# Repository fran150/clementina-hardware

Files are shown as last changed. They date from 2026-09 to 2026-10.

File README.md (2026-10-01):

# Clementina Hardware

KiCad 9 schematic and board for Clementina, a 3.3 V homebrew computer built
around a W65C02S CPU. A Raspberry Pi Pico 2 W, called MIA, runs the machine: it
generates the CPU clock, boots the kernel, and provides video, audio, storage
and input.

Status: the rev 1 schematic is complete and ERC-clean, and the rev 1 board is
laid out, fully routed and DRC-clean. The first build is planned on
protoboard, using the same parts as the board.

## Opening the project

Open `clementina-hardware.kicad_pro` in KiCad 9.

- `clementina.kicad_sym` (listed in `sym-lib-table`) holds the parts KiCad's
  own libraries lack, currently the AS6C62256 SRAM.
- The W65C02S and W65C22S symbols come from KiCad's Plugin and Content Manager
  (library `PCM_65xx-library`). The schematic carries copies, so it opens
  without that library. Install it to keep ERC's library check clean.
- One ERC item is excluded on purpose: the Pico's AGND tied to GND. The ADC is
  unused, and the Pico datasheet allows the join.
- `clementina-hardware.kicad_dru` holds one custom DRC rule: the audio jack's
  barrel hangs over the board edge on purpose, so its silkscreen outline may
  cross the edge.
- DRC shows one warning, and it is expected: the Pico footprint "does not
  match the copy in the library". The library's antenna keep-out lists 32
  copper layers, and a 2-layer board keeps only two of them.

Sheets:

| Sheet | Contents |
| --- | --- |
| `clementina-hardware.kicad_sch` (A3) | CPU, VIA, RAM, MIA, IRQ and reset circuits, expansion headers, user port, audio output, microSD, power and decoupling |
| `CS Logic.kicad_sch` | Address decoding (74AC138 x2, 74AC08, two gates of the 74AC00) |
| `OE_RW_PHI2_Sync.kicad_sch` | Read and write strobes: `~OE` from R/W, `~WE` qualified by PHI2 (two gates of the 74AC00) |

## Architecture

| Part | Role |
| --- | --- |
| W65C02S (U1) | CPU. MIA drives PHI2: 1.2 MHz by default, up to 8 MHz. |
| AS6C62256 (U4) | 32 KB base RAM |
| AS6C4008 (U2) | 512 KB extended RAM, seen through a 16 KB window |
| W65C22S (U3) | VIA. Port A selects the extended RAM bank; port B and CA/CB go to the user port. |
| Raspberry Pi Pico 2 W (A1) | MIA: clock, boot loader, video over Wi-Fi, audio, microSD, input, reset |
| 74AC138 x2, 74AC08, 74AC00 | Glue logic (see [Glue logic timing](#glue-logic-timing)) |

Memory map:

| Range | Device |
| --- | --- |
| `$0000-$7FFF` | Base RAM |
| `$8000-$BFFF` | Extended RAM window (32 banks, selected by VIA PA0-PA4) |
| `$C000-$DFFF` | I/O: eight 1 KB slots. Slot 0 (`$C000`) is the VIA; slots 1-7 go to the expansion headers. |
| `$E000-$FFFF` | MIA (registers at `$FFE0-$FFFF`) |

MIA's pins:

| GPIO | Signal |
| --- | --- |
| GP0-GP3 | microSD (SPI0: MISO, CS, SCK, MOSI) |
| GP4, GP5 | Audio left and right (PWM) |
| GP6 | MIA chip select |
| GP7 | R/W |
| GP8-GP15 | D0-D7 |
| GP16-GP20 | A0-A4 |
| GP21 | PHI2 |
| GP22 | IRQ |
| GP26 | RESB (MIA holds the CPU and VIA in reset) |
| GP27 | Reset request from the RESET button |
| GP28 | Unused |

### Glue logic timing

The glue logic is 74AC, not 74HC, because 74HC is slow at 3.3 V (roughly
13 ns per gate typical, up to about 30 ns). Two places depend on it:

- **Write strobe.** `~WE = NAND(PHI2, ~OE)` in one 74AC00 gate, so `~WE`
  rises within about 10 ns of PHI2 falling. The W65C02S only guarantees its
  address and data for 10 ns after PHI2 falls, and the SRAMs need both held
  until `~WE` rises. This timing doesn't depend on clock speed, so running
  slower doesn't help. The Picocomputer RP6502 makes WE# the same way.
- **Chip selects.** The VIA and the expansion cards need their chip select
  10 ns before PHI2 rises. U6 is enabled straight from A13-A15 (A15
  through one inverting gate), not through U8, which removes a decoder level
  from those selects.

With 74AC parts, the chip-select paths meet the datasheets up to about
6.5 MHz with worst-case parts, and typical parts reach 8 MHz. 74HC parts give
the same logic but lose the write-strobe guarantee, and the VIA's chip select
limits them to about 3.5 MHz worst case.

Interrupts are wired-AND: MIA and the VIA each pull `~IRQB` low through a BAT85
Schottky diode against a 4.7 kΩ pull-up. `~NMI` (4.7 kΩ) and RDY (2.2 kΩ) are
also pulled up, so expansion cards can use them. RDY is also an output: the
CPU pulls it low while it executes `WAI`. The W65C02S only guarantees 1.6 mA
at 0.4 V there, so the RDY pull-up can't be stronger than about 2 kΩ.

## Power (rev 1)

Everything runs from the Pico's USB. Its 3V3 output supplies the whole board,
and VBUS supplies the `+5V` pins on the headers.

- Keep the external 3.3 V load under about 300 mA. The board uses roughly
  50 mA idle and 150 mA with the microSD card writing, which leaves about
  150 mA for expansion cards.
- A phone charger works when no PC is attached.
- VSYS is left free for a rev 2 power input.

## Connectors

**J1, J2: expansion bus** (2x20 keyed box headers, identical)

| Pin | Signal | Pin | Signal |
| ---: | --- | ---: | --- |
| 1 | GND | 2 | +3.3V |
| 3 | A0 | 4 | A1 |
| 5 | A2 | 6 | A3 |
| 7 | A4 | 8 | A5 |
| 9 | A6 | 10 | A7 |
| 11 | A8 | 12 | A9 |
| 13 | GND | 14 | PHI2 |
| 15 | GND | 16 | RWB |
| 17 | ~OE | 18 | ~WE |
| 19 | ~RESB | 20 | ~IRQB |
| 21 | ~NMI | 22 | RDY |
| 23 | D0 | 24 | D1 |
| 25 | D2 | 26 | D3 |
| 27 | D4 | 28 | D5 |
| 29 | D6 | 30 | D7 |
| 31 | ~IOCS1 | 32 | ~IOCS2 |
| 33 | ~IOCS3 | 34 | ~IOCS4 |
| 35 | ~IOCS5 | 36 | ~IOCS6 |
| 37 | ~IOCS7 | 38 | +5V |
| 39 | GND | 40 | +3.3V |

**J3: user port** (2x10 keyed box header, VIA port B)

| Pin | Signal | Pin | Signal |
| ---: | --- | ---: | --- |
| 1 | GND | 2 | +3.3V |
| 3 | PB0 | 4 | PB1 |
| 5 | PB2 | 6 | PB3 |
| 7 | PB4 | 8 | PB5 |
| 9 | PB6 | 10 | PB7 |
| 11 | CB1 | 12 | CB2 |
| 13 | CA1 | 14 | CA2 |
| 15 | ~RESB | 16 | GND |
| 17 | GND | 18 | +5V |
| 19 | GND | 20 | +3.3V |

Rules for cards on J1-J3:

- 3.3 V logic only. Never put a 5 V signal on any pin.
- A card claims one I/O slot by jumpering one of `~IOCS1`-`~IOCS7`.
- `~IRQB`, `~NMI` and RDY: pull them low through a Schottky diode or an
  open-drain output, and never drive them high.
- RDY also goes low while the CPU executes `WAI`. Don't read RDY low as a
  wait request from another card.
- `~RESB` is driven by MIA: read it, never drive it.
- W65C22S port pins have no current limiting. Drive LEDs and similar loads
  through a resistor.

**J4: audio out.** A stereo 3.5 mm jack (CUI SJ1-3533NG, through-hole, round
pins): tip left, ring right. Each channel
uses the same output stage as the Picocomputer RP6502: a 220 Ω / 100 Ω
divider, a 100 nF filter capacitor, a 47 µF DC block and a 1.8 kΩ bleed
resistor. It gives about 1 Vpp line level and drives headphones directly. MIA
mixes at 48 kHz.

**J5: microSD.** A 1x9 female header for the Adafruit 4682 microSD breakout
(3 V only), used in SPI mode on MIA's SPI0: 400 kHz to initialise, then
12 MHz. The breakout has its own pull-ups (CS, MISO, DAT1, DAT2) and bypass
capacitors. DAT1, DAT2 and card detect stay unconnected.

| Pin | 1 | 2 | 3 | 4 | 5 | 6 | 7 | 8 | 9 |
| --- | --- | --- | --- | --- | --- | --- | --- | --- | --- |
| Breakout | 3V | GND | CLK | SO | SI | CS | DAT1 | DAT2 | DET |
| Signal | +3.3V | GND | SD_SCK | SD_MISO | SD_MOSI | SD_CS | - | - | - |

## Board (rev 1)

`clementina-hardware.kicad_pcb`: 172.7 x 108.6 mm, 2 layers, every part
through-hole. The chips sit in sockets and the Pico plugs into female headers,
so the same parts move from the protoboard build to the board.

- Layout: the MIA Pico is at the top left, with its USB port on the top edge
  and its Wi-Fi antenna over a copper keep-out. The microSD breakout sits to
  its left, with the card slot at the left board edge. The audio stage and jack
  run down the left edge, and the reset button sits well below the Pico. The CPU,
  RAM, extended RAM and VIA form one row, with the user port at the right edge.
  The glue logic is in a row below them, and the two expansion headers are
  stacked along the bottom edge.
- Every chip has a 100 nF capacitor next to its supply pin; C14 (22 µF) is by
  the Pico's 3V3 pin.
- Wi-Fi antenna: Raspberry Pi recommends putting the Pico W's antenna at a
  board edge with nothing close to it. Here it sits inside the board, as on the
  Picocomputer RP6502. The Pico stands about 10 mm up on its headers, no copper
  runs under the antenna, and a rule area ("Wi-Fi antenna clearance") keeps
  tracks, vias and ground fill about 6 mm past the Pico's end. Leave that area
  clear of parts and cables. The expected cost is a few dB of range, which the
  video protocol tolerates. To check a build, compare the Wi-Fi signal
  strength (RSSI) of the Pico on its own and on the board at the same spot; if
  the board costs more than about 6 dB, move the antenna to an edge in rev 2.
- Routing: 0.25 mm signal tracks, 0.4 mm for GND, +3.3V and +5V (net class
  `Power`), 0.2 mm clearance, and 0.6 / 0.3 mm vias. The top layer runs mostly
  horizontal and the bottom mostly vertical. Both layers carry a GND pour,
  stitched with vias. Any hobby PCB fab can make it (1.6 mm FR-4, 1 oz copper).
- The routing was produced by a script and then checked with KiCad's DRC and
  its schematic parity check. Edit it freely in KiCad.
- Silkscreen: part values are printed on the resistors and capacitors, and the
  chip names inside the socket outlines. The J5 pin names and the breakout's
  outline are printed too.
- Mounting: four M3 holes in the corners. Two M2.5 holes under the microSD
  breakout match its own holes. They're optional, to support it with
  standoffs (about 11 mm).

### Bill of materials

Every part has two schematic fields that keep the bill of materials generic,
so you can source parts yourself (for the protoboard build) or hand them to an
assembly service:

- **Factory**: what gets soldered to the board at that designator. Chips get a
  DIP socket, and the Pico (A1) gets two 1x20 female headers.
- **Plug-in**: what you plug in afterwards, if anything.

[`bom/factory-bom.csv`](bom/factory-bom.csv) lists everything that's
soldered: passives, diodes, sockets, headers, the jack and the button. With
those soldered (by you or the factory), the board needs no more soldering;
plug in these parts:

| Ref | Part |
| --- | --- |
| U1 | WDC W65C02S CPU, DIP-40 (W65C02S6TPG-14) |
| U3 | WDC W65C22S VIA, DIP-40 (W65C22S6TPG-14) |
| U4 | Alliance AS6C62256-55PCN, 32K x 8 SRAM, DIP-28 |
| U2 | Alliance AS6C4008-55PCN, 512K x 8 SRAM, DIP-32 |
| U6, U8 | 74AC138, DIP-16 |
| U7 | 74AC08, DIP-14 |
| U9 | 74AC00, DIP-14 |
| A1 | Raspberry Pi Pico 2 WH (the version with pins already soldered) |
| J5 | Adafruit 4682 microSD breakout, 3 V |

The Adafruit 4682 ships with its header loose: solder the 9 pins to the
module once, or use a breakout sold with the header fitted.

The "A1" row of the factory BOM is two headers, one per side of the Pico.

To regenerate the factory BOM after changing parts:

```
kicad-cli sch export bom --fields 'Factory,${QUANTITY},Reference' --labels 'Part,Qty,References' --group-by Factory --sort-field Reference --sort-asc -o bom/factory-bom.csv clementina-hardware.kicad_sch
```

### Fabrication files

The Gerbers are generated from the board, so they aren't committed: git
ignores `fabrication/`. Rebuild them after any board change:

```
mkdir -p fabrication/gerbers
kicad-cli pcb export gerbers --no-x2 --no-netlist --subtract-soldermask -l F.Cu,B.Cu,F.Mask,B.Mask,F.Silkscreen,Edge.Cuts -o fabrication/gerbers/ clementina-hardware.kicad_pcb
kicad-cli pcb export drill --excellon-separate-th -o fabrication/gerbers/ clementina-hardware.kicad_pcb
rm fabrication/gerbers/*.gbrjob
zip -j -FS fabrication/clementina-rev1-gerbers.zip fabrication/gerbers/*
```

Upload `fabrication/clementina-rev1-gerbers.zip` to the fab. It holds eight
files: both copper layers, both masks, the front silkscreen, the board outline,
and separate drill files for plated and unplated holes.

- `--no-x2 --no-netlist`: PCBWay's KiCad guide asks for Gerbers without X2
  attributes. With them, its upload preview showed only the holes.
- No back silkscreen: it's empty.
- `--subtract-soldermask` keeps silkscreen ink off the pads.
- The zip leaves out KiCad's `.gbrjob` job file.
- `zip -FS` also removes files that are no longer in `fabrication/gerbers/`.

When you order boards, tag the commit you ordered from and attach the zip you
uploaded to a GitHub release on that tag. That keeps a record of exactly what
was made.

## Not in rev 1

- A separate power input (USB-C into VSYS) with a jumper to power a USB
  keyboard on the Pico's port
- Local video output, likely a second Pico as a display client

## Related repositories

- [clementina-6502](https://github.com/fran150/clementina-6502): emulator
- [clementina-mia](https://github.com/fran150/clementina-mia): MIA firmware
- [clementina-rom](https://github.com/fran150/clementina-rom): kernel,
  BASIC and WozMon
- [clementina-sdk](https://github.com/fran150/clementina-sdk): development SDK
- [clementina-studio](https://github.com/fran150/clementina-studio): asset
  editor
- [clementina-video-client](https://github.com/fran150/clementina-video-client):
  video client

## License

GPLv3. See [LICENSE](LICENSE).

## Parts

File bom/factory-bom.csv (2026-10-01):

Part | Qty | References
2 x female header 1x20, 2.54 mm, 8.5 mm tall (both at A1, one per Pico side) | 1 | A1
Ceramic capacitor 1 µF, 50 V, X7R, radial, 5.08 mm lead spacing | 1 | C1
Electrolytic capacitor 22 µF, 16 V, radial, 5 mm diameter, 2.5 mm lead spacing | 1 | C14
Ceramic capacitor 100 nF, 50 V, X7R, radial, 5.08 mm lead spacing | 10 | C2,C4,C6-C13
Electrolytic capacitor 47 µF, 16 V, radial, 5 mm diameter, 2.5 mm lead spacing | 2 | C3,C5
BAT85 Schottky diode, DO-34 | 2 | D1,D2
IDC box header 2x10, 2.54 mm, vertical | 1 | J3
3.5 mm stereo jack, CUI SJ1-3533NG or same footprint | 1 | J4
Female header 1x9, 2.54 mm, 8.5 mm tall | 1 | J5
IDC box header 2x20, 2.54 mm, vertical | 2 | J1,J2
Resistor 2.2 kΩ, 1/4 W, 1% metal film, axial, 10.16 mm lead spacing | 1 | R1
Resistor 10 kΩ, 1/4 W, 1% metal film, axial, 10.16 mm lead spacing | 1 | R3
Resistor 4.7 kΩ, 1/4 W, 1% metal film, axial, 10.16 mm lead spacing | 2 | R2,R5
Resistor 100 Ω, 1/4 W, 1% metal film, axial, 10.16 mm lead spacing | 3 | R4,R7,R10
Resistor 220 Ω, 1/4 W, 1% metal film, axial, 10.16 mm lead spacing | 2 | R6,R9
Resistor 1.8 kΩ, 1/4 W, 1% metal film, axial, 10.16 mm lead spacing | 2 | R8,R11
Tactile switch 6 x 6 mm, through-hole | 1 | SW1
DIP-32 socket, 15.24 mm (0.6 in) rows | 1 | U2
DIP-28 socket, 15.24 mm (0.6 in) rows | 1 | U4
DIP-40 socket, 15.24 mm (0.6 in) rows | 2 | U1,U3
DIP-16 socket, 7.62 mm (0.3 in) rows | 2 | U6,U8
DIP-14 socket, 7.62 mm (0.3 in) rows | 2 | U7,U9

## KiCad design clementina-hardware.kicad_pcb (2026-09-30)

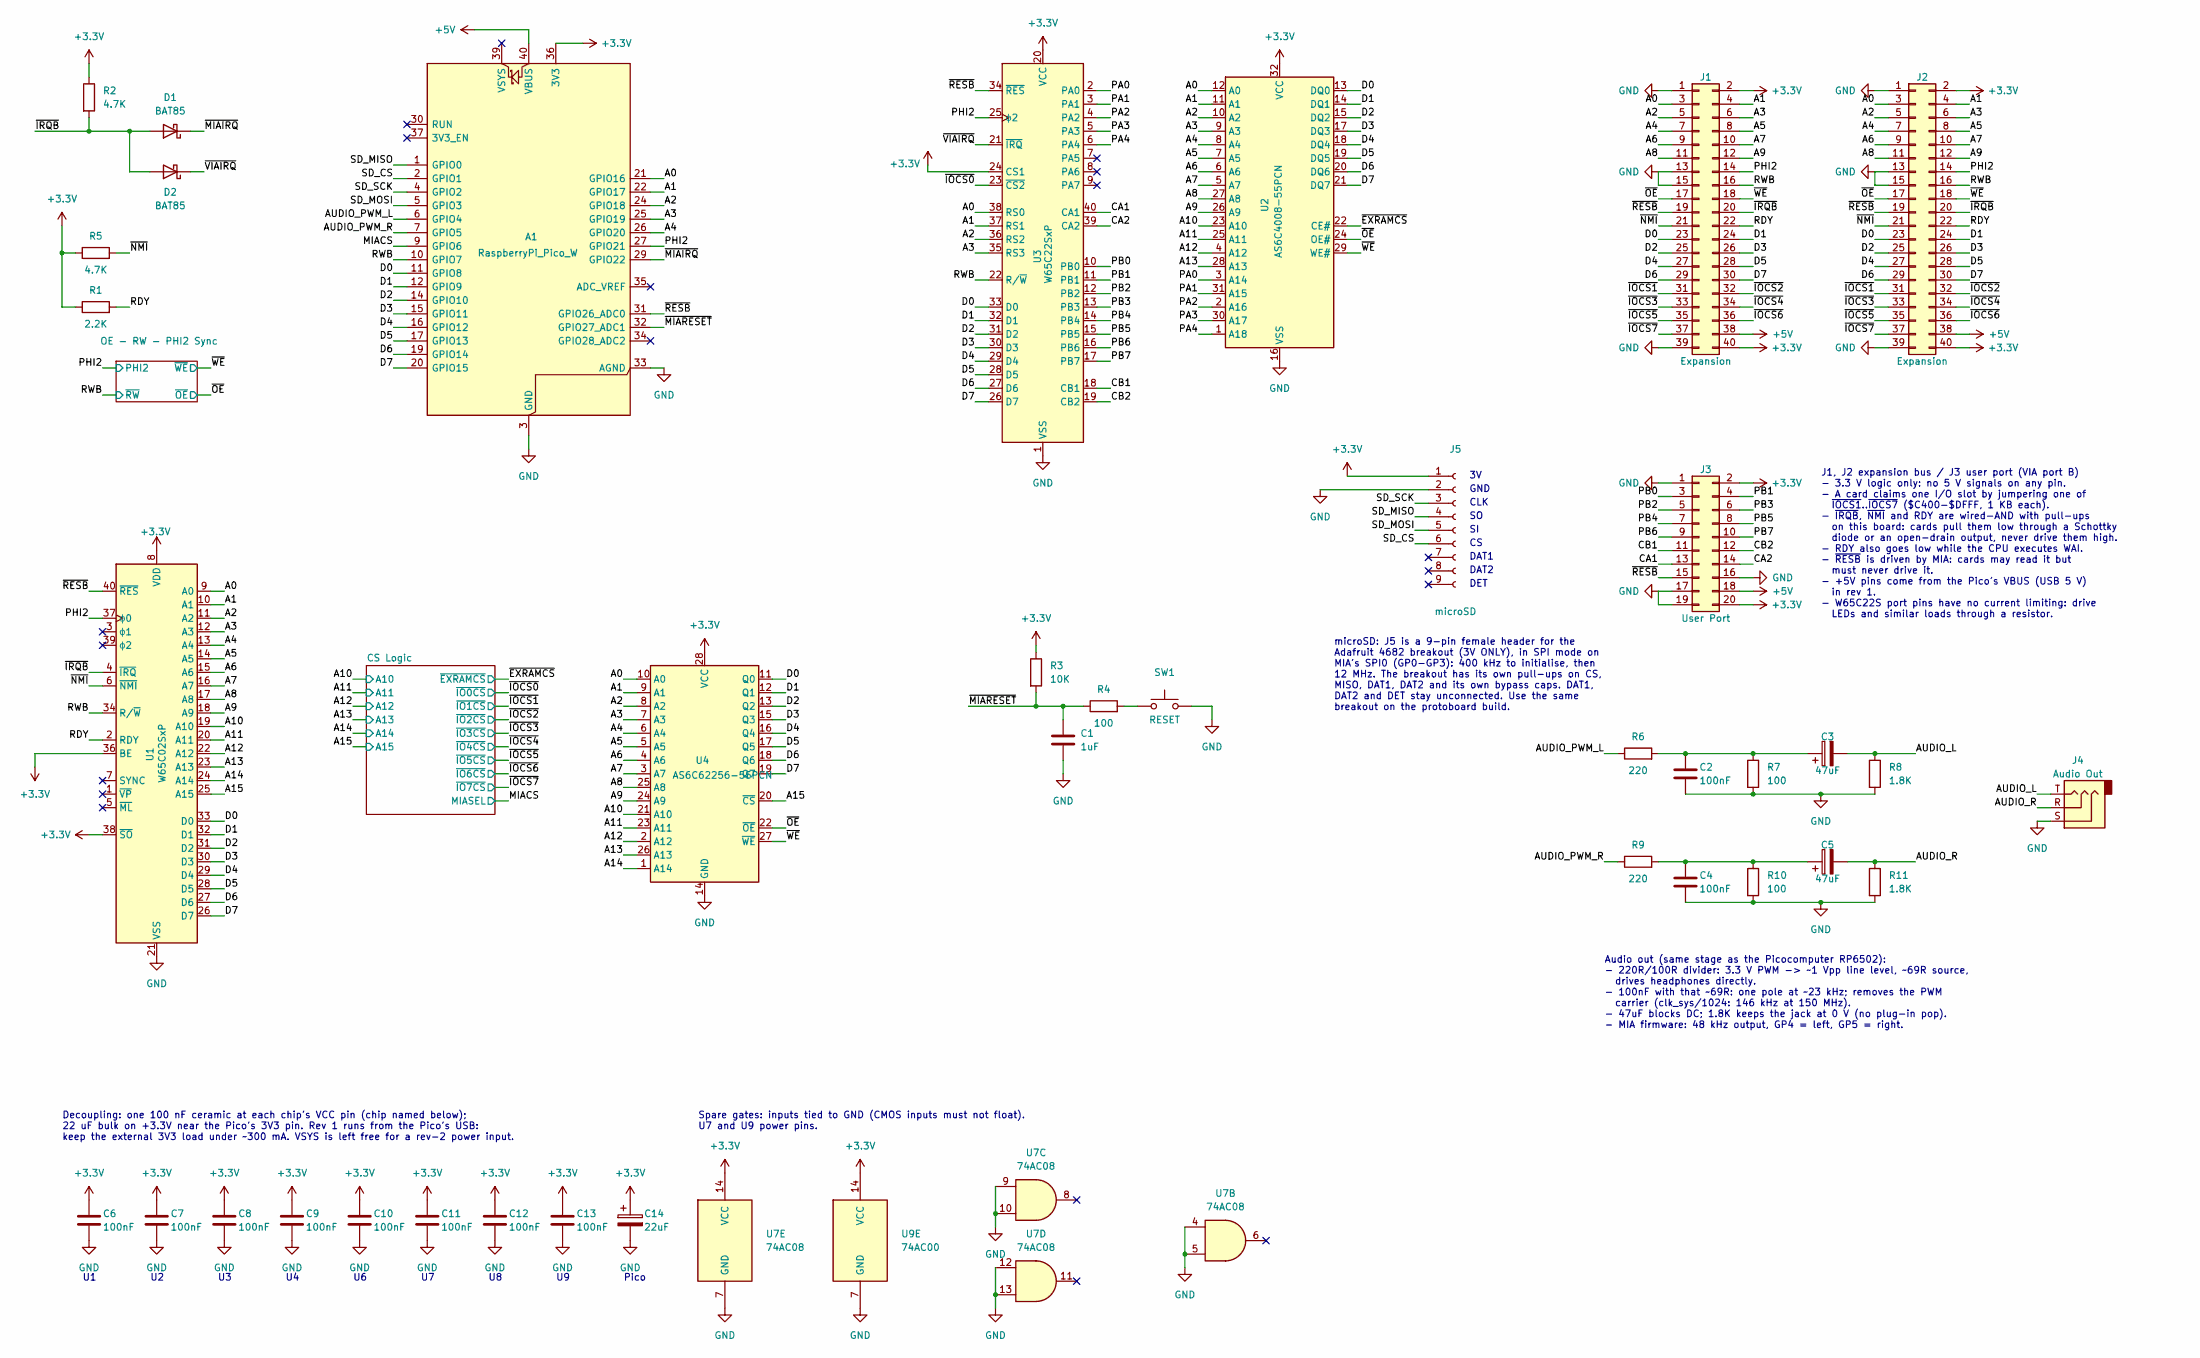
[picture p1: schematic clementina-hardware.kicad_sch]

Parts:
A1: RaspberryPi_Pico_W; RaspberryPi_Pico_Common_THT
C1: 1uF; C_Disc_D5.0mm_W2.5mm_P5.00mm
C2, C4, C6, C7, C8, C9, C10, C11, C12, C13: 100nF; C_Disc_D5.0mm_W2.5mm_P5.00mm
C3, C5: 47uF; CP_Radial_D5.0mm_P2.50mm
C14: 22uF; CP_Radial_D5.0mm_P2.50mm
D1, D2: BAT85; D_DO-34_SOD68_P7.62mm_Horizontal
J1, J2: Expansion; IDC-Header_2x20_P2.54mm_Vertical
J3: User Port; IDC-Header_2x10_P2.54mm_Vertical
J4: Audio Out; Jack_3.5mm_CUI_SJ1-3533NG_Horizontal_CircularHoles
J5: microSD; PinSocket_1x09_P2.54mm_Vertical
R1: 2.2K; R_Axial_DIN0207_L6.3mm_D2.5mm_P10.16mm_Horizontal
R2, R5: 4.7K; R_Axial_DIN0207_L6.3mm_D2.5mm_P10.16mm_Horizontal
R3: 10K; R_Axial_DIN0207_L6.3mm_D2.5mm_P10.16mm_Horizontal
R4, R7, R10: 100; R_Axial_DIN0207_L6.3mm_D2.5mm_P10.16mm_Horizontal
R6, R9: 220; R_Axial_DIN0207_L6.3mm_D2.5mm_P10.16mm_Horizontal
R8, R11: 1.8K; R_Axial_DIN0207_L6.3mm_D2.5mm_P10.16mm_Horizontal
SW1: RESET; SW_PUSH_6mm
U1: W65C02SxP; DIP-40_W15.24mm_Socket
U2: AS6C4008-55PCN; DIP-32_W15.24mm_Socket
U3: W65C22SxP; DIP-40_W15.24mm_Socket
U4: AS6C62256-55PCN; DIP-28_W15.24mm_Socket
U7: 74AC08; DIP-14_W7.62mm_Socket
U9: 74AC00; DIP-14_W7.62mm_Socket

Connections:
+3.3V: A1.36 (3V3), C6.1, C7.1, C8.1, C9.1, C10.1, C11.1, C12.1, C13.1, C14.1, J1.2, J1.40, J2.2, J2.40, J3.2, J3.20, J5.1, R1.1, R2.1, R3.1, R5.1, U1.8 (VDD), U1.36 (BE), U1.38 (~SO), U2.32 (VCC), U3.20 (VCC), U3.24 (CS1), U4.28 (VCC), U7.14 (VCC), U9.14 (VCC); also elsewhere on the board
+5V: A1.40 (VBUS), J1.38, J2.38, J3.18
/A0: A1.21 (GPIO16), J1.3, J2.3, U1.9 (A0), U2.12 (A0), U3.38 (RS0), U4.10 (A0)
/A1: A1.22 (GPIO17), J1.4, J2.4, U1.10 (A1), U2.11 (A1), U3.37 (RS1), U4.9 (A1)
/A2: A1.24 (GPIO18), J1.5, J2.5, U1.11 (A2), U2.10 (A2), U3.36 (RS2), U4.8 (A2)
/A3: A1.25 (GPIO19), J1.6, J2.6, U1.12 (A3), U2.9 (A3), U3.35 (RS3), U4.7 (A3)
/A4: A1.26 (GPIO20), J1.7, J2.7, U1.13 (A4), U2.8 (A4), U4.6 (A4)
/A5: J1.8, J2.8, U1.14 (A5), U2.7 (A5), U4.5 (A5)
/A6: J1.9, J2.9, U1.15 (A6), U2.6 (A6), U4.4 (A6)
/A7: J1.10, J2.10, U1.16 (A7), U2.5 (A7), U4.3 (A7)
/A8: J1.11, J2.11, U1.17 (A8), U2.27 (A8), U4.25 (A8)
/A9: J1.12, J2.12, U1.18 (A9), U2.26 (A9), U4.24 (A9)
/A10: U1.19 (A10), U2.23 (A10), U4.21 (A10); also elsewhere on the board
/A11: U1.20 (A11), U2.25 (A11), U4.23 (A11); also elsewhere on the board
/A12: U1.22 (A12), U2.4 (A12), U4.2 (A12); also elsewhere on the board
/A13: U1.23 (A13), U2.28 (A13), U4.26 (A13); also elsewhere on the board
/A14: U1.24 (A14), U4.1 (A14); also elsewhere on the board
/A15: U1.25 (A15), U4.20 (~CS); also elsewhere on the board
/AUDIO_L: C3.2, J4.T, R8.1
/AUDIO_PWM_L: A1.6 (GPIO4), R6.1
/AUDIO_PWM_R: A1.7 (GPIO5), R9.1
/AUDIO_R: C5.2, J4.R, R11.1
/CA1: J3.13, U3.40 (CA1)
/CA2: J3.14, U3.39 (CA2)
/CB1: J3.11, U3.18 (CB1)
/CB2: J3.12, U3.19 (CB2)
/D0: A1.11 (GPIO8), J1.23, J2.23, U1.33 (D0), U2.13 (DQ0), U3.33 (D0), U4.11 (Q0)
/D1: A1.12 (GPIO9), J1.24, J2.24, U1.32 (D1), U2.14 (DQ1), U3.32 (D1), U4.12 (Q1)
/D2: A1.14 (GPIO10), J1.25, J2.25, U1.31 (D2), U2.15 (DQ2), U3.31 (D2), U4.13 (Q2)
/D3: A1.15 (GPIO11), J1.26, J2.26, U1.30 (D3), U2.17 (DQ3), U3.30 (D3), U4.15 (Q3)
/D4: A1.16 (GPIO12), J1.27, J2.27, U1.29 (D4), U2.18 (DQ4), U3.29 (D4), U4.16 (Q4)
/D5: A1.17 (GPIO13), J1.28, J2.28, U1.28 (D5), U2.19 (DQ5), U3.28 (D5), U4.17 (Q5)
/D6: A1.19 (GPIO14), J1.29, J2.29, U1.27 (D6), U2.20 (DQ6), U3.27 (D6), U4.18 (Q6)
/D7: A1.20 (GPIO15), J1.30, J2.30, U1.26 (D7), U2.21 (DQ7), U3.26 (D7), U4.19 (Q7)
/MIACS: A1.9 (GPIO6); also elsewhere on the board
/PA0: U2.3 (A14), U3.2 (PA0)
/PA1: U2.31 (A15), U3.3 (PA1)
/PA2: U2.2 (A16), U3.4 (PA2)
/PA3: U2.30 (A17), U3.5 (PA3)
/PA4: U2.1 (A18), U3.6 (PA4)
/PB0: J3.3, U3.10 (PB0)
/PB1: J3.4, U3.11 (PB1)
/PB2: J3.5, U3.12 (PB2)
/PB3: J3.6, U3.13 (PB3)
/PB4: J3.7, U3.14 (PB4)
/PB5: J3.8, U3.15 (PB5)
/PB6: J3.9, U3.16 (PB6)
/PB7: J3.10, U3.17 (PB7)
/PHI2: A1.27 (GPIO21), J1.14, J2.14, U1.37 (ϕ0), U3.25 (ϕ2); also elsewhere on the board
/RDY: J1.22, J2.22, R1.2, U1.2 (RDY)
/RWB: A1.10 (GPIO7), J1.16, J2.16, U1.34 (R/~W), U3.22 (R/~W); also elsewhere on the board
/SD_CS: A1.2 (GPIO1), J5.6
/SD_MISO: A1.1 (GPIO0), J5.4
/SD_MOSI: A1.5 (GPIO3), J5.5
/SD_SCK: A1.4 (GPIO2), J5.3
/~EXRAMCS: U2.22 (CE#); also elsewhere on the board
/~IOCS0: U3.23 (~CS2); also elsewhere on the board
/~IOCS1: J1.31, J2.31; also elsewhere on the board
/~IOCS2: J1.32, J2.32; also elsewhere on the board
/~IOCS3: J1.33, J2.33; also elsewhere on the board
/~IOCS4: J1.34, J2.34; also elsewhere on the board
/~IOCS5: J1.35, J2.35; also elsewhere on the board
/~IOCS6: J1.36, J2.36; also elsewhere on the board
/~IOCS7: J1.37, J2.37; also elsewhere on the board
/~IRQB: D1.2 (A), D2.2 (A), J1.20, J2.20, R2.2, U1.4 (~IRQ)
/~MIAIRQ: A1.29 (GPIO22), D1.1 (K)
/~MIARESET: A1.32 (GPIO27_ADC1), C1.1, R3.2, R4.1
/~NMI: J1.21, J2.21, R5.2, U1.6 (~NMI)
/~OE: J1.17, J2.17, U2.24 (OE#), U4.22 (~OE); also elsewhere on the board
/~RESB: A1.31 (GPIO26_ADC0), J1.19, J2.19, J3.15, U1.40 (~RES), U3.34 (~RES)
/~VIAIRQ: D2.1 (K), U3.21 (~IRQ)
/~WE: J1.18, J2.18, U2.29 (WE#), U4.27 (~WE); also elsewhere on the board
GND: A1.3 (GND), A1.8 (GND), A1.13 (GND), A1.18 (GND), A1.23 (GND), A1.28 (GND), A1.33 (AGND), A1.38 (GND), C1.2, C2.2, C4.2, C6.2, C7.2, C8.2, C9.2, C10.2, C11.2, C12.2, C13.2, C14.2, J1.1, J1.13, J1.15, J1.39, J2.1, J2.13, J2.15, J2.39, J3.1, J3.16, J3.17, J3.19, J4.S, J5.2, R7.2, R8.2, R10.2, R11.2, SW1.2, U1.21 (VSS), U2.16 (VSS), U3.1 (VSS), U4.14 (GND), U7.4, U7.5, U7.7 (GND), U7.9, U7.10, U7.12, U7.13, U9.7 (GND); also elsewhere on the board
unnamed: C2.1, C3.1, R6.2, R7.1
unnamed: C4.1, C5.1, R9.2, R10.1
unnamed: R4.2, SW1.1

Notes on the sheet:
GND
CLK
DAT1
DAT2
DET
microSD: J5 is a 9-pin female header for the Adafruit 4682 breakout (3V ONLY), in SPI mode on MIA's SPI0 (GP0-GP3): 400 kHz to initialise, then 12 MHz. The breakout has its own pull-ups on CS, MISO, DAT1, DAT2 and its own bypass caps. DAT1, DAT2 and DET stay unconnected. Use the same breakout on th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
Spare gates: inputs tied to GND (CMOS inputs must not float). U7 and U9 power pins.
Pico
Decoupling: one 100 nF ceramic at each chip's VCC pin (chip named below); 22 uF bulk on +3.3V near the Pico's 3V3 pin. Rev 1 runs from the Pico's USB: keep the external 3V3 load under ~300 mA. VSYS is left free for a rev-2 power input.
Audio out (same stage as the Picocomputer RP6502): - 220R/100R divider: 3.3 V PWM -> ~1 Vpp line level, ~69R source, drives headphones directly. - 100nF with that ~69R: one pole at ~23 kHz; removes the PWM carrier (clk_sys/1024: 146 kHz at 150 MHz). - 47uF blocks DC; 1.8K keeps the jack at 0 V (no 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
J1, J2 expansion bus / J3 user port (VIA port B) - 3.3 V logic only: no 5 V signals on any pin. - A card claims one I/O slot by jumpering one of ~{IOCS1}..~{IOCS7} ($C400-$DFFF, 1 KB each). - ~{IRQB}, ~{NMI} and RDY are wired-AND with pull-ups on this board: cards pull them low through a Schottky d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

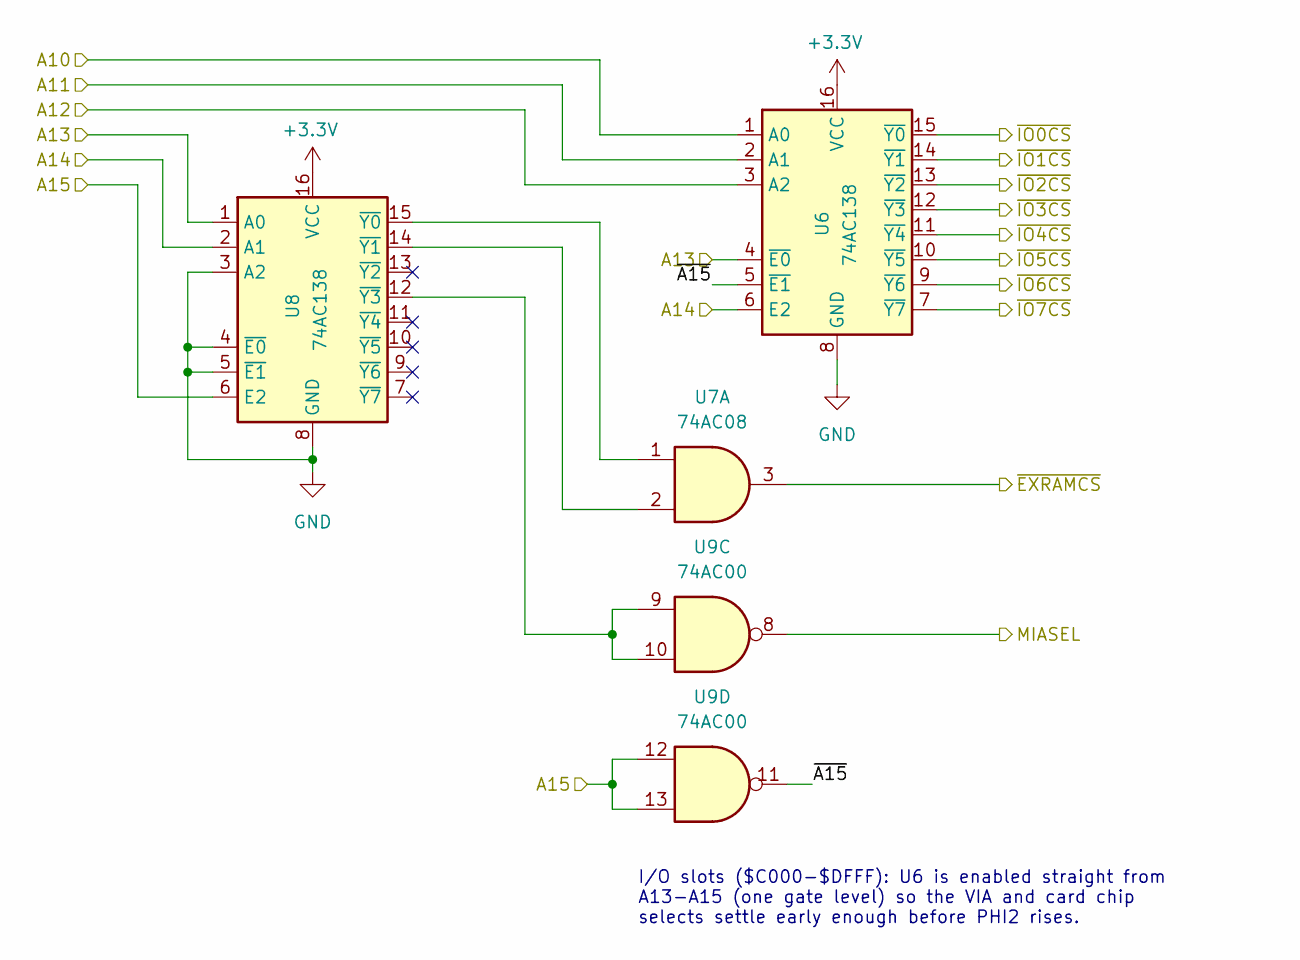
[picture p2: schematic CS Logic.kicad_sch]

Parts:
U6, U8: 74AC138; DIP-16_W7.62mm_Socket
U7: 74AC08; DIP-14_W7.62mm_Socket
U9: 74AC00; DIP-14_W7.62mm_Socket

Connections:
+3.3V: U6.16 (VCC), U8.16 (VCC); also elsewhere on the board
/A10: U6.1 (A0); also elsewhere on the board
/A11: U6.2 (A1); also elsewhere on the board
/A12: U6.3 (A2); also elsewhere on the board
/A13: U6.4 (~E0), U8.1 (A0); also elsewhere on the board
/A14: U6.6 (E2), U8.2 (A1); also elsewhere on the board
/A15: U8.6 (E2), U9.12, U9.13; also elsewhere on the board
/CS Logic/~A15: U6.5 (~E1), U9.11
/MIACS: U9.8; also elsewhere on the board
/~EXRAMCS: U7.3; also elsewhere on the board
/~IOCS0: U6.15 (~Y0); also elsewhere on the board
/~IOCS1: U6.14 (~Y1); also elsewhere on the board
/~IOCS2: U6.13 (~Y2); also elsewhere on the board
/~IOCS3: U6.12 (~Y3); also elsewhere on the board
/~IOCS4: U6.11 (~Y4); also elsewhere on the board
/~IOCS5: U6.10 (~Y5); also elsewhere on the board
/~IOCS6: U6.9 (~Y6); also elsewhere on the board
/~IOCS7: U6.7 (~Y7); also elsewhere on the board
GND: U6.8 (GND), U8.3 (A2), U8.4 (~E0), U8.5 (~E1), U8.8 (GND); also elsewhere on the board
unnamed: U7.1, U8.15 (~Y0)
unnamed: U7.2, U8.14 (~Y1)
unnamed: U8.12 (~Y3), U9.9, U9.10

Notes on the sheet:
I/O slots ($C000-$DFFF): U6 is enabled straight from A13-A15 (one gate level) so the VIA and card chip selects settle early enough before PHI2 rises.

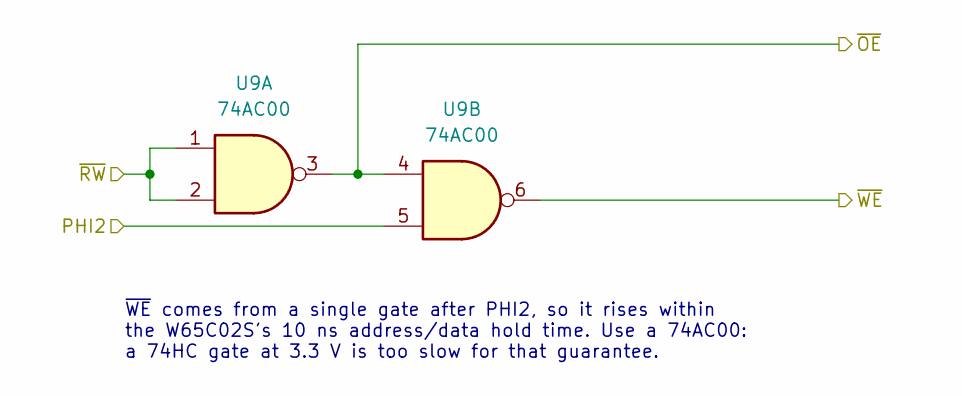
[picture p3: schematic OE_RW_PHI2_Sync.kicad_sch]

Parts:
U9: 74AC00; DIP-14_W7.62mm_Socket

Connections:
/PHI2: U9.5; also elsewhere on the board
/RWB: U9.1, U9.2; also elsewhere on the board
/~OE: U9.3, U9.4; also elsewhere on the board
/~WE: U9.6; also elsewhere on the board

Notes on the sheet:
~{WE} comes from a single gate after PHI2, so it rises within the W65C02S's 10 ns address/data hold time. Use a 74AC00: a 74HC gate at 3.3 V is too slow for that guarantee.

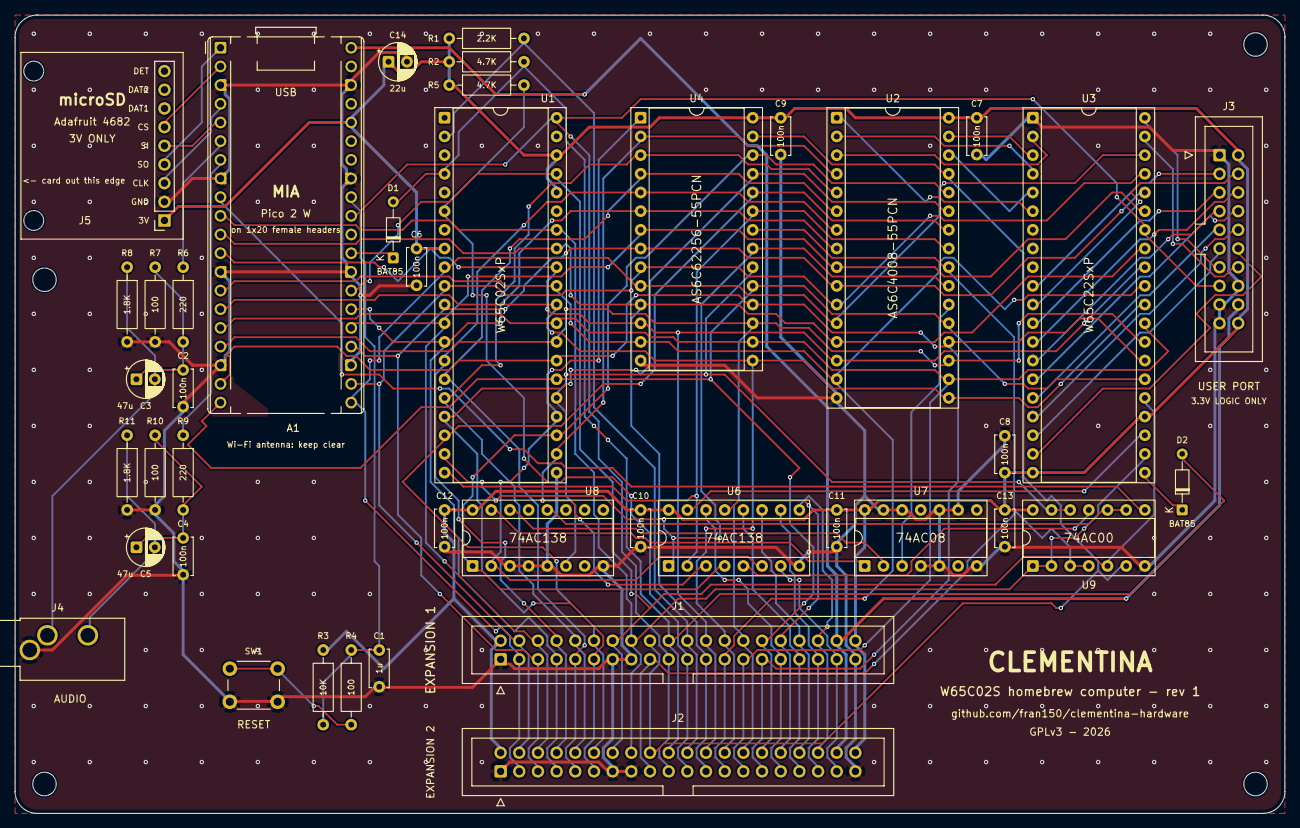
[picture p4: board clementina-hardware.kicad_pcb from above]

Board: 2 copper layers, 172.7 x 108.6 mm, 48 parts (0 on the bottom side), 80 nets.

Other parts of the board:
H1, H2, H3, H4: MountingHole_3.2mm_M3
H5, H6: MountingHole_2.7mm_M2.5

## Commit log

2026-09-30 Initial commit: Clementina 6502 schematic
    The KiCad 9 project for the Clementina 6502 computer: W65C02S, W65C22S VIA,
    32 KB base RAM plus 512 KB banked extended RAM, and a Raspberry Pi Pico 2 W
    as MIA. It includes the CS Logic and OE/RW/PHI2 sync sub-sheets.
    The main sheet (A3) is drawn with net labels at the pins instead of buses.
    It includes:
    - a diode-OR IRQ with a 4.7K pull-up
    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
    [CS Logic.kicad_sch, OE_RW_PHI2_Sync.kicad_sch, clementina-hardware.kicad_pcb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]
2026-09-30 Rev 1 power section: run everything from the Pico's USB
    - Pico 3V3 drives +3.3V, VBUS drives +5V for the header pins, and all
    GND pins plus AGND go to GND. VSYS is left free for a rev 2 power input.
    RUN, 3V3_EN, ADC_VREF and GP28 get no-connect flags.
    - Decoupling: 100 nF per chip (C6-C13, each labelled with its chip) and
    22 uF bulk on +3.3V (C14).
    - U5's only AND gate moves into U7's spare slot (U7B), and U5 is removed.
    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
    [CS Logic.kicad_sch, OE_RW_PHI2_Sync.kicad_sch, clementina-hardware.kicad_sch]
2026-09-30 Add the microSD card and clear the remaining ERC items
    - J5 microSD on MIA's SPI0 (GP0-GP3) in SPI mode. RN1 (4 x 10K bussed)
    pulls up CS, MISO, DAT1 and DAT2. C15 100 nF and C16 10 uF at the socket
    absorb insertion surges. A note covers building it with a 3V-only
    breakout on protoboard.
    - PA5-PA7 get no-connect flags instead of dangling labels. W65C22S pins
    have bus-hold, so they don't float.
    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
    [clementina-hardware.kicad_sch]
2026-09-30 Add README and GPLv3 license
    The README describes the rev 1 schematic: how to open it, the sheets, the
    architecture, memory map and MIA pin map, power, connector pinouts, rules
    for expansion cards, what rev 1 leaves out, and the related repositories.
    The license is the same GPLv3 text the other Clementina repositories use.
2026-09-30 All through-hole parts: footprints, microSD breakout socket, round-pin jack
    - Every part now has a through-hole footprint: DIP sockets for the chips,
    the Pico on 1x20 female headers (RaspberryPi_Pico_Common_THT), axial
    resistors and diodes, disc and radial capacitors, a 6 mm tactile switch.
    - J5 is now a 1x9 female header for the Adafruit 4682 microSD breakout
    (3V, GND, CLK, SO, SI, CS, DAT1, DAT2, DET). The breakout has its own
    pull-ups and bypass caps, so RN1, C15 and C16 are gone. DAT1, DAT2 and
    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
    [CS Logic.kicad_sch, OE_RW_PHI2_Sync.kicad_sch, clementina-hardware.kicad_sch]
2026-09-30 Rev 1 board: 2-layer through-hole layout, fully routed
    - 172.7 x 108.6 mm, 2 layers. Pico at the top left (USB on the top edge,
    antenna over a keep-out), microSD breakout beside it with the card at the
    left edge, audio and jack down the left edge, CPU/RAM/ext RAM/VIA in a
    row, glue logic below, J1/J2 stacked on the bottom edge, J3 on the right.
    - 0.25 mm signals, 0.4 mm Power net class (GND, +3.3V, +5V), 0.2 mm
    clearance, 0.6/0.3 mm vias; GND pours on both layers with stitching vias.
    - Silkscreen: values on passives, chip names in the socket outlines,
    connector labels, J5 pin names and the breakout's outline.
    - Four M3 mounting holes, two M2.5 holes for the breakout's standoffs.
    -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
    [clementina-hardware.kicad_pcb]
2026-09-30 Glue logic: /WE from one NAND gate, flat I/O decode, 74AC parts
    The write strobe went PHI2 -> 74HC08 -> 74HC04 -> /WE: about 26 ns typical
    and up to ~65 ns at 3.3 V before /WE rose, against the W65C02S's 10 ns
    address/data hold. With U4's /CE tied to A15, a store followed by an
    access to another RAM address could also write that address.
    - U9 is now a 74AC00 (quad NAND): ~OE = NAND(RWB, RWB),
    ~WE = NAND(PHI2, ~OE), MIASEL = NAND(~Y3, ~Y3), ~A15 = NAND(A15, A15).
    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
    [CS Logic.kicad_sch, OE_RW_PHI2_Sync.kicad_sch, clementina-hardware.kicad_sch]
2026-09-30 Board: re-route for the reworked glue logic
    Same placement; U9 (now 74AC00) and U6's enables re-routed. DRC: no
    errors, no unconnected items, no schematic parity issues (only the known
    Pico library-mismatch warning). 122 vias, down from 137.
    [clementina-hardware.kicad_pcb]
2026-09-30 README: 74AC glue logic and why
    Parts tables list 74AC138 x2, 74AC08 and 74AC00, and a new "Glue logic
    timing" section explains the one-gate write strobe, the flat I/O decode
    and the speed each logic family supports at 3.3 V.
2026-09-30 Tie the CPU's /SO to +3.3V
    /SO (pin 38) had a no-connect flag. It is an input: a falling edge sets
    the V flag, and WDC's datasheet requires unused input-only pins to be tied
    to VDD, so a floating /SO could flip V at random (BVS/BVC after ADC, SBC,
    BIT). It now goes to +3.3V like BE. The board is re-routed for the new
    connection: DRC clean, no unconnected items, no parity issues.
    [clementina-hardware.kicad_pcb, clementina-hardware.kicad_sch]
2026-09-30 RDY pull-up: 1K -> 2.2K
    RDY is bidirectional: the W65C02S pulls it low while it executes WAI, and
    it only guarantees 1.6 mA at 0.4 V. Against 1K that would be ~2.9 mA and a
    low level of roughly 0.65 V, out of spec. 2.2K keeps it at 1.5 mA. The
    cost is a slower rise when a card releases RDY (~130 ns with ~50 pF),
    harmless at the default 1.2 MHz and at most one extra wait state at 8 MHz.
    The header note and README also warn card designers that RDY goes low
    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
    [clementina-hardware.kicad_pcb, clementina-hardware.kicad_sch]
2026-09-30 Clear the area past the Wi-Fi antenna
    Raspberry Pi recommends the Pico W's antenna at a board edge with nothing
    close to it. Moving it there would reshape the board, so for rev 1 the
    nearest intrusions go instead:
    - The reset button and its RC (R3, R4, C1) sat ~6 mm past the antenna's
    end; they move ~30 mm away, left of J1.
    - A rule area ("Wi-Fi antenna clearance") on both layers keeps tracks,
    vias and GND fill ~6 mm past the Pico's end, extending the footprint's
    own antenna keep-out. The silkscreen says to keep it clear.
    Re-routed: DRC clean, no unconnected items, no schematic parity issues.
    The README explains the trade-off and how to check a build (RSSI with and
    without the board;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
    [clementina-hardware.kicad_pcb]
2026-10-01 Generic bill of materials for a solder-free build
    Every part gets two hidden schematic fields:
    - Factory: what is soldered at that designator, in generic terms (resistor
    value/size/pitch, capacitor type and lead spacing, DIP socket size for each
    chip, two 1x20 female headers for the Pico, box headers, jack, switch).
    - Plug-in: what goes in afterwards (the chips, a Pico 2 WH with its pins
    pre-soldered, the Adafruit 4682).
    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
    [CS Logic.kicad_sch, OE_RW_PHI2_Sync.kicad_sch, clementina-hardware.kicad_sch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]
2026-10-01 Ignore generated fabrication files; document the working export
    fabrication/ holds the Gerbers, drill files and zip generated from the
    board, so git now ignores it.
    The README's fabrication commands now reproduce the zip prepared for
    ordering:
    - no X2 attributes or netlist
    - front silkscreen only, with the soldermask subtracted from it
    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

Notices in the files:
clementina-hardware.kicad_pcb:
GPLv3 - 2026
